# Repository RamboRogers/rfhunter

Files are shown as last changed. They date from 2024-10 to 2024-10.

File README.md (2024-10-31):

# RFHunter V4.0

This project is an RF Signal Scanner built using an ESP32, AD8317 RF detector, and various other components. It's designed to detect and measure RF signals in the environment and display the signal strength on an OLED display. It's useful to find hidden cameras, wiretapping devices, and other RF-enabled devices.

<center>RFHunter V4.0
</center>

See the video here: https://x.com/rogerscissp/status/1847721651359850985

## Updates

2024-10-30 First Tag from the Wild! [RFHunter on X](https://x.com/LukeSwitzer_/status/1851430655499919486)

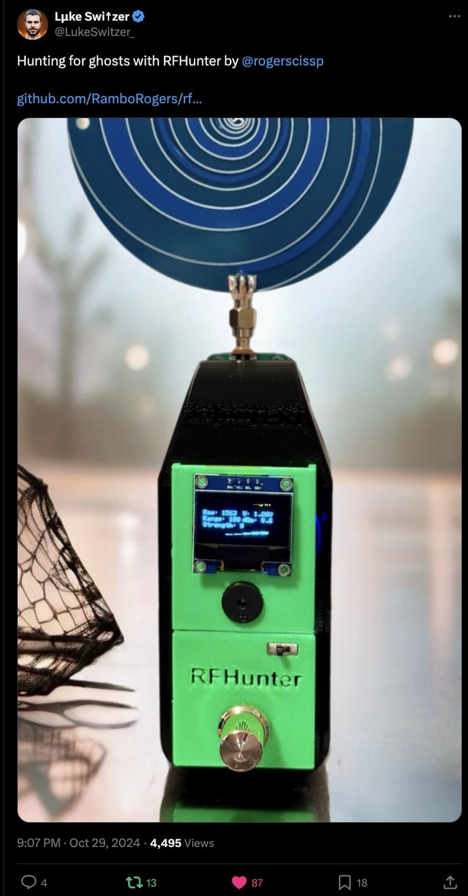
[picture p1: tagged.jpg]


2024-10-28 RFHunter hit #1 on hackernews this week!
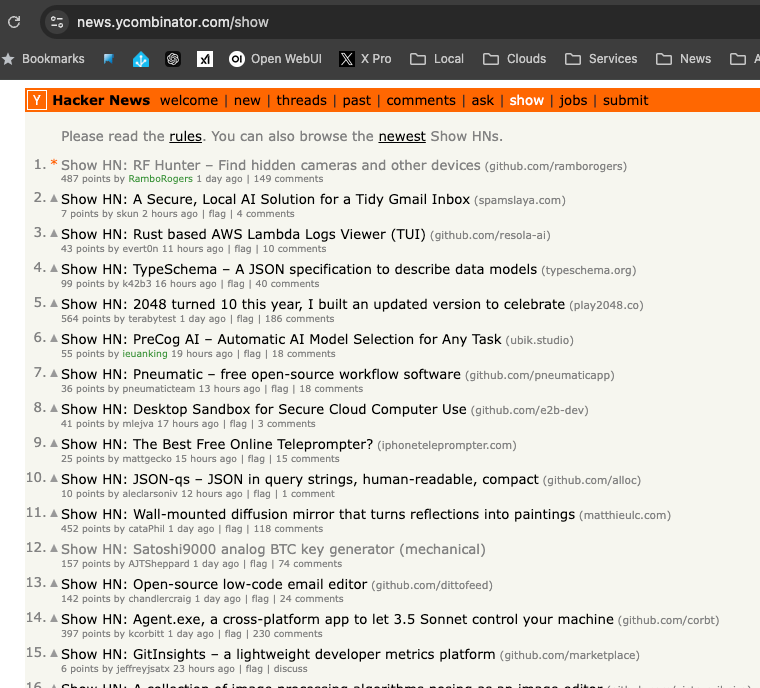
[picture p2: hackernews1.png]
Hacker News


I've have a number of interesting products in the works.  I'll share more details soon.

> **Note:** I've had some interesting comments under the issues section of this repo.  If you're making one of these you may want to look. It was suggest you could modif this board to not need a boost converter.  I've not tried this yet but I may give it a shot.  If you do please let me know how it goes.

## Ready for Primetime

V4 here snaps together with zero tools, has space in the bottom for a battery, and a charge controller, and in place of the 9V battery you have a boost converter.  Now you only need 1 battery, and it should last weeks or months depending on usage cycles.

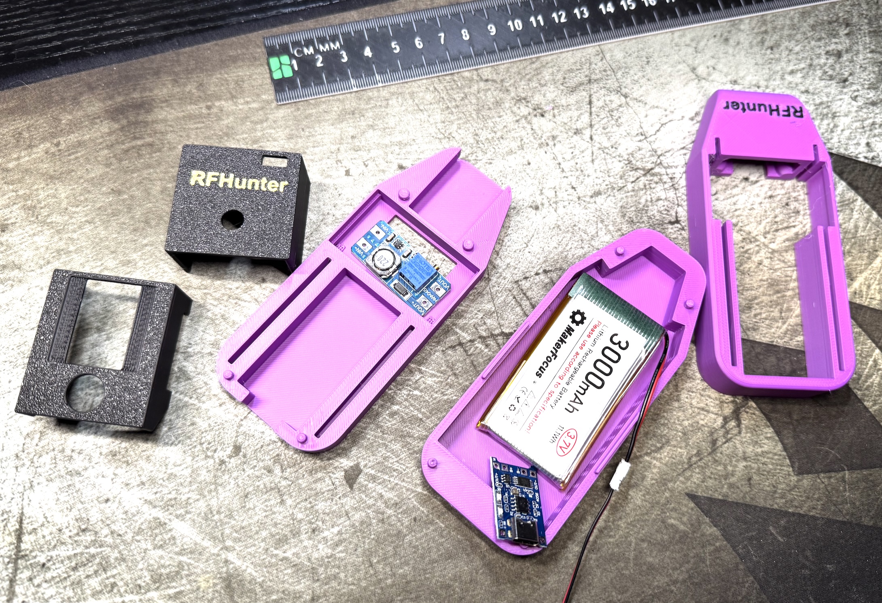
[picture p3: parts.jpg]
Parts


## Author

Matthew Rogers a simple hacker from the United States.
- Website: [matthewrogers.org](https://matthewrogers.org)
- Twitter: [@rogerscissp](https://x.com/rogerscissp)
- LinkedIn: [Matthew Rogers](https://www.linkedin.com/in/matthewrogerscissp/)

## License

This project is licensed under the GNU General Public License v3.0 (GNU GPLv3). See the [LICENSE](LICENSE) file for details.

## Bill of Materials (BOM)

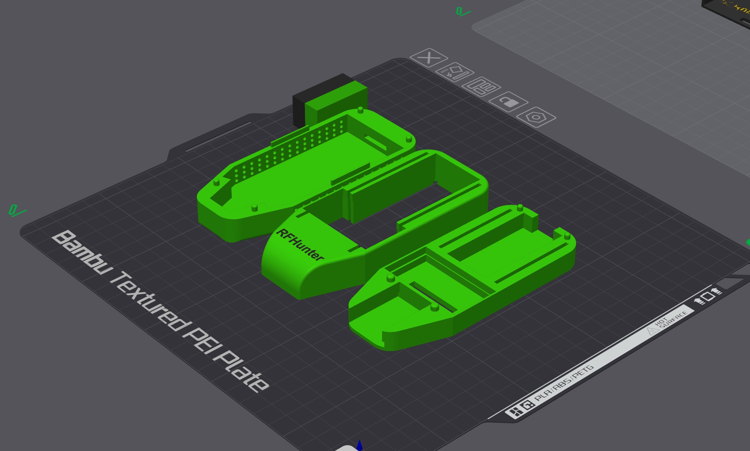
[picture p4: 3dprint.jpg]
3D Printed Parts


I listed the Amazon links in the .cpp file if you want to buy the parts. These are not affiliate links. You can buy these anywhere.

1. ESP32 Development Board
2. AD8317 RF Power Detector
3. TP4056 Lithium Battery Charge Controller
3.7V Lithium-ion Battery
4. Boost Converter (3.3V to 9V)
5. OLED Display (I2C, 128x64)
6. Potentiometer (10k)
7. Piezo Buzzer
8. Power Switch

## Build Process

1. Assemble the power circuit:
   - Connect the battery to the TP4056 charge controller
   - Connect the out from theTP4056 output to the power switch
   - Connect the power switch output to the ESP32 5v VIN and boost converter input
   - Adjust the boost converter output to 9V

  > Make sure the boost converter is set to 9V. If you don't have a boost converter, you can use a 9V battery.

  > Make sure you use the 5V VIN and not the 3.3V VIN.

2. Connect the AD8317 RF detector:
   - Power the AD8317 with the 9V output from the boost converter
   - Connect the VOUT pin to ESP32 GPIO 34

3. Set up the OLED display:
   - Connect VCC to ESP32 3.3V
   - Connect GND to ESP32 GND
   - Connect SDA to ESP32 GPIO 21
   - Connect SCL to ESP32 GPIO 22

4. Connect the potentiometer:
   - Connect VCC to ESP32 3.3V
   - Connect GND to ESP32 GND
   - Connect the wiper to ESP32 GPIO 35

5. Connect the piezo buzzer:
   - Connect the positive terminal to ESP32 GPIO 5
   - Connect the negative terminal to ESP32 GND

6. Flash the ESP32 with the provided code:

   ```
   git clone https://github.com/ramborogers/rfhunter.git
   cd rfhunter
   pio run -t upload
   ```
   >**You shouldn't need to change any of the code.**

7. Snap the case together

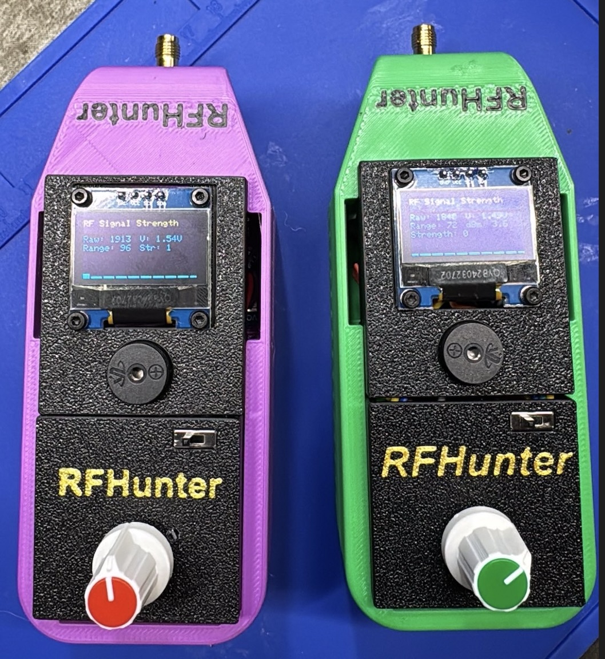
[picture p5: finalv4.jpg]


## Wiring Instructions

Wiring Guide for RFHunter:

### Power Circuit:
1. Battery (3.7V) positive terminal -> Power Switch
2. Power Switch -> TP4056 Charge Controller (B+)
3.TP4056 OUT+ -> ESP32 VIN and Boost Converter IN+
4. Boost Converter OUT+ (adjusted to 9V) -> AD8317 VCC
5. Battery negative terminal -> TP4056 B- and ESP32 GND and Boost Converter IN-
6. Boost Converter OUT- -> AD8317 GND

### Signal and Control:

7. AD8317 VOUT -> ESP32 GPIO 34 (RF_SENSOR_PIN)
8. Potentiometer VCC -> ESP32 3.3V
9. Potentiometer GND -> ESP32 GND
Potentiometer Wiper -> ESP32 GPIO 35 (POT_PIN)
10. OLED Display VCC -> ESP32 3.3V
11. OLED Display GND -> ESP32 GND
12. OLED Display SDA -> ESP32 GPIO 21 (OLED_SDA)
13. OLED Display SCL -> ESP32 GPIO 22 (OLED_SCL)
14. Piezo Buzzer positive -> ESP32 GPIO 5 (BUZZER_PIN)
15. Piezo Buzzer negative -> ESP32 GND

## Notes:

- The power switch controls the main power flow from the battery.
- The TP4056 charge controller manages battery charging and protection.
- The boost converter steps up the 3.3V from the battery to 9V for the AD8317 sensor.
- All GND connections should be common.
Double-check all connections and voltage levels before powering on.

## Usage

1. Power on the device using the power switch
2. The OLED display will show the current RF signal strength
3. Use the potentiometer to adjust the sensitivity
4. The piezo buzzer will sound when strong RF signals are detected

## Improvements and Feedback

We're always looking for ways to improve this project. If you have any ideas or suggestions, please feel free to open an issue or submit a pull request on our GitHub repository.

If you build your own RF Signal Scanner based on this project, we'd love to see it! Please share your creation on Twitter/X and tag @rogerscissp. Your feedback and experiences are valuable to the community!

Happy building!

Matthew Rogers

> The best idea for a date, his and hers RF Hunters!

<center>
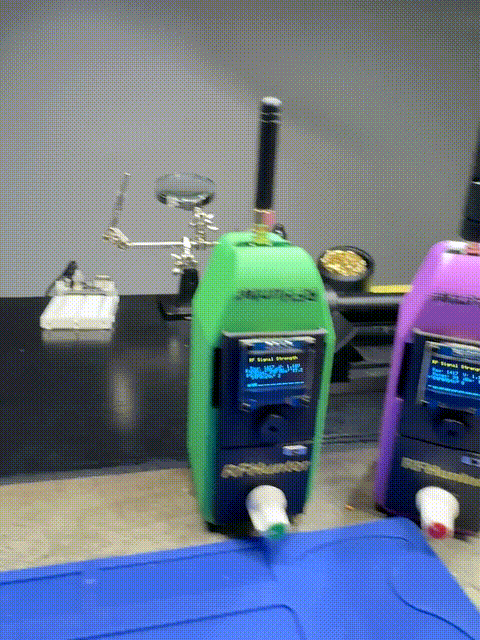
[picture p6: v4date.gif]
RFHunter V4.0

</center>

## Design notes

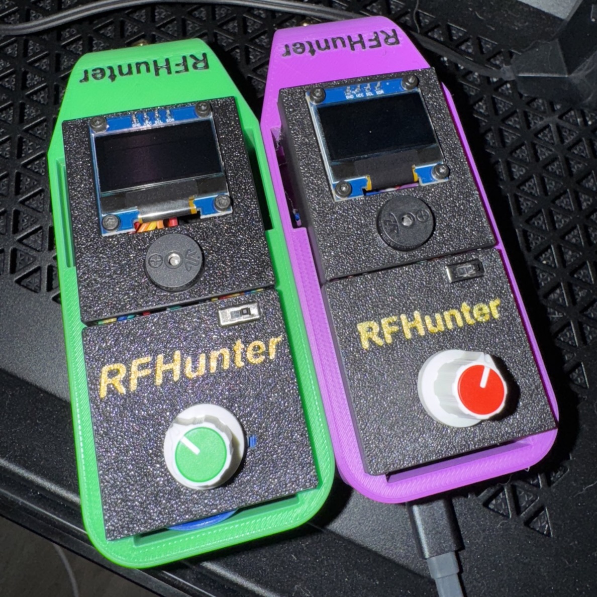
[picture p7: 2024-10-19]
built.jpg

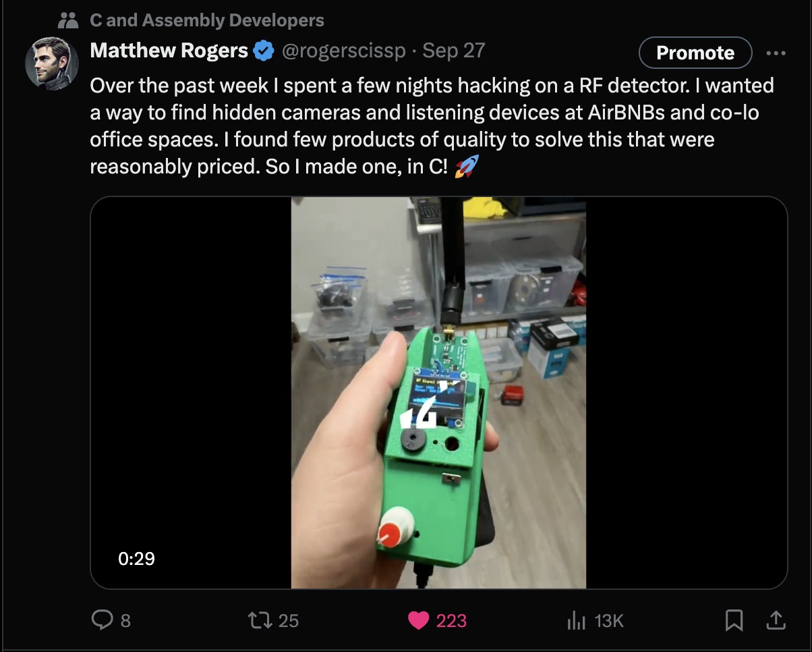
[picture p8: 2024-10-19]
xpost.jpg

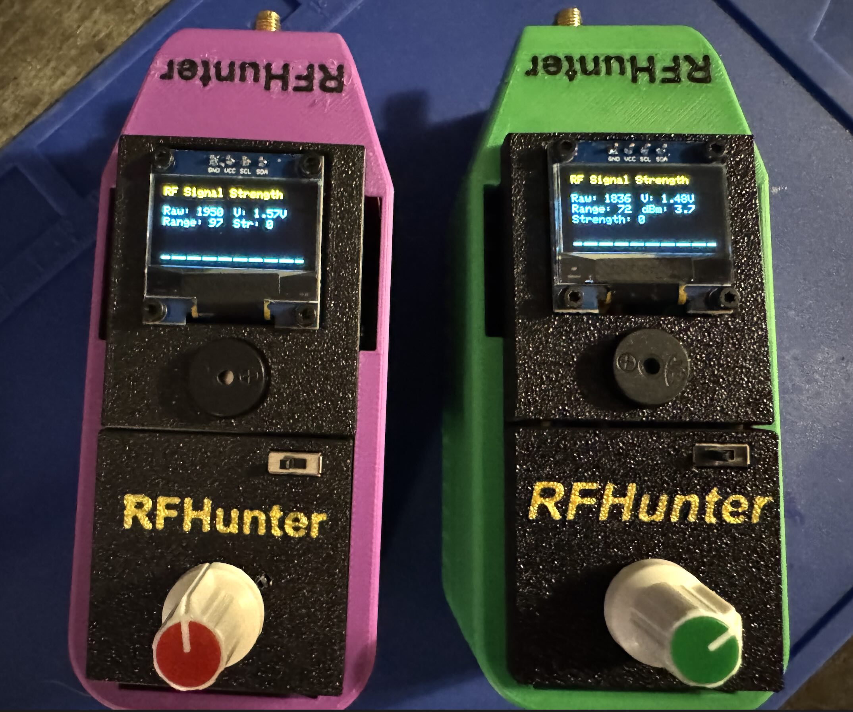
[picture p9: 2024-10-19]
builtv4.jpg

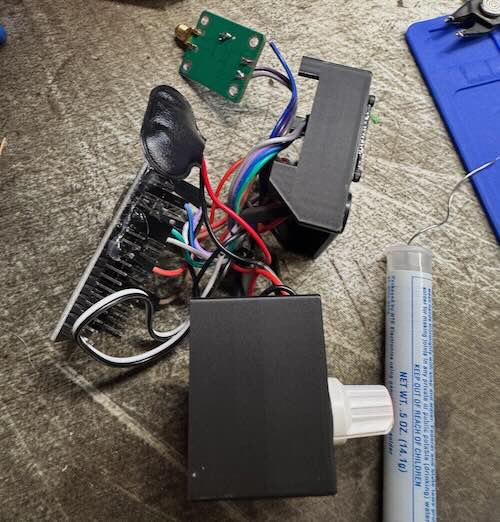
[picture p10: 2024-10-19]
wires.jpg

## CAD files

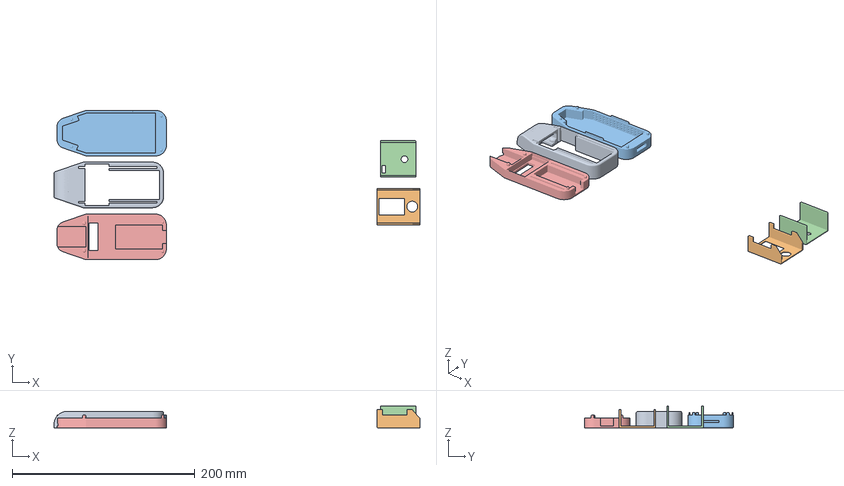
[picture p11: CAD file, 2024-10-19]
RFHunter-3DPrint-v10.3mf
400.8 x 163.6 x 24.0 mm
Top Hand
Grip
BatteryBox
BackTop
Middle

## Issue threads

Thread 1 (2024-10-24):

Bost converter isn't needed.

Kalrkloss, 2024-10-24:
The AD8317 itself can work from 3.0 to 5.5V.
The board you're using has a 5V regulator (78L05), that needs an input voltage of at least 7V.
If you replace the voltage regulator by a jumper wire, you can omit the boost converter, and also save some power.
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

EspressoTini, 2024-10-26:
Was just going to say the same, 9v not needed.  This chip would also be sweet on a credit card size pcb, coin cell battery, and LEDs for the signal stregth, for portability.  Maybe the antenna could be pcb too

RamboRogers, 2024-10-28:
Thats a cool idea!  I don't know the underlying design of the board, I just use it as a signal source.

RamboRogers, 2024-10-28:
Added note to README

lukeswitz, 2024-10-28:
I’m curious why this issue is closed.

Wow, this thing is huge! Its like a 90’s cordless phone. This could all be done on a single layer. Anyhow- the problem is indeed an issue from any objective electrical perspective. But if you’re ok with it “just working” then close away.

Removing the unit and jumping those pads indeed saves power and eliminates the need for the boost controller (that’s very prone to blowing the pot and worse from a simple search). Eliminating a point of failure and decreasing power consumption - win/win. At least link a reliable step-up to 9v or something.

Link to this closed issue in the readme perhaps. Good luck!

Closed 2024-10-28.

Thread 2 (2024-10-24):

How would this deal with all IoT gadgets?

X-Ryl669, 2024-10-24:
Since now house are filled with IoT stuff, emitting Zigbee, Wifi, Bluetooth, LoRa and so on, how does this gizmo can make a difference between a genuine gadget and camera?

What about the non RF camera that are storing the video on a local µSD card without being RF connected?

How about a cameras in a main appliance object (like a SmartTV or a sattelite receiver, which will emit RF anyway)?

Kalrkloss, 2024-10-24:
The IoT stuff usually sends only short bursts of data here and there, while an active camera sends a continuous stream of data, resulting in a constantly high field strength. You'll notice the difference.

X-Ryl669, 2024-10-24:
> You'll notice the difference.

Only if there's a client on the camera, which is extremely unlikely to happen at the time you're using the detector.

> Big surprise you cannot detect non-RF camera with RF detector, lol.

Well, my point is that the main page is trying to "sell" the idea that the device will detect cameras. But it won't.
Non RF camera will be undetected and RF camera won't likely be detected either (except in the very unlikely event that a client is connected and streaming from the camera at the exact time you're scanning the room).

But if you peak a WIFI burst (or any other radio burst), then it's even more likely it comes from the IoT gizmos than the camera itself. All devices (IoT and RF Camera) will have some (sparse) chatty transmission for maintaining their RF link, so there's ~ zero reason the RF activity is actually linked with a camera (well, close to zero in fact).

So maybe the main page should be modified to state that this is actually a RF detector for any RF emission in its receiving range and remove the part that reads `It's useful to find hidden cameras, wiretapping devices, and other RF-enabled devices.` because I don't see how you'll find hidden cameras with the detector, or a wiretapping device that, by definition will not use RF if they are wired.

Also, since there's no dual antenna, you can't trilaterate the signal either so, at best, you'll get a pseudo range to the source (since you don't know the source power, you can only make relative measurement => better / worse). Good luck finding a device that's emitting its WIFI beacon every 10s that way, with all the reflections.

BTW, I'm not criticizing the amazing work you've done. Just that the subtitle is misleading.

I think it should say something like "This device is able to detect RF emission, and measure the relative RF power received".

X-Ryl669, 2024-10-24:
> And if you really mean it, you need "Non-linear Junction Detector", prepare at least $10k. ;-)

When I was younger, I made a simple device that's detecting the electromagnetic field intensity. I was based on a cheap 1N4148 diode and a op amp + $1  micro controller (using its DAC and ADC). The basic physical principle was to bias the diode very close to the tripping point and ramp it up periodically. The "avalanche" effect, where the current grows exponentially triggers from ambient EM field (plus temperature, plus ..., but RF field effect is observable and temperature is usually constant).
By periodically counting the time it takes for the diode to become conductive, you get a signal proportional to RF activity.

The overall cost for the device was very low. I've just lost interest with playing with it very fast.

You can search for diode RF tester for simple schematic from the very basic to the most efficient design.

RamboRogers, 2024-10-26:
This device detects long streams and signals.  I don't care about short bursts.  It's also barelines on bootup so it will alert off baseline.  If you turn it on directly next to AP it's unlikely it will alarm much after.  You want to power it on and it will alert as you get close to a higher signal versus baseline.

Closed 2024-10-26.

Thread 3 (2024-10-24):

Battery voltage

michaelmior, 2024-10-24:
The README appears to have a typo.

> If you don't have a **<ins>9V battery</ins>**, you can use a **<ins>9V battery</ins>**.

RamboRogers, 2024-10-26:
Thanks, fixed.

Closed 2024-10-26.

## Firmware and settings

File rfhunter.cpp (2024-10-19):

#include <Arduino.h>
#include <Wire.h>
#include <Adafruit_GFX.h>
#include <Adafruit_SSD1306.h>
#include <math.h>

/*

RFHunter V4.01

Code is property of Matthew Rogers, 2024 matthewrogers.org
This code is free to use under the GNU GPLv3 license.

https://x.com/rogerscissp

2024-10-19 V4.01 - Added a display recovery mechanism in case the display is not found on startup.

*/

/*
I'm including the parts I used in the BOM. I've included links to Amazon, but these are not affiliate links. You can buy these anywhere.

The attached 3mf file is the case I designed in Fusion 360. You'll want to use supports to print it, but it's aligned on the bed properly in two separate plates. All of these parts clip in perfectly.

Parts
1. ESP-WROOM-32 - https://www.amazon.com/gp/product/B08D5ZD528
2. AD8317 - https://www.amazon.com/gp/product/B07FHZXTCZ
3. 10k Potentiometer - https://www.amazon.com/gp/product/B0CSW6D1N4
5. 3000mah Battery - https://www.amazon.com/gp/product/B08T6GT7DV
6. Charge Controller - https://www.amazon.com/gp/product/B08DNK398S
7. Boost Converter - https://www.amazon.com/gp/product/B09S8ZDVBN
8. 128x64 OLED Display - https://www.amazon.com/gp/product/B0D2RLXLBZ
9. Piezo Buzzer - https://www.amazon.com/Cylewet-Terminals-Electronic-Electromagnetic-Impedance/dp/B01NCOXB2Q
10. Power Switch - https://www.amazon.com/gp/product/B007QAJUUS

Consumables and Tools
1. Dupont Wires - https://www.amazon.com/gp/product/B01EV70C78
2. Solder and Soldering Iron - https://www.amazon.com/gp/product/B0CZ94B328
3. Wire Stripper - https://www.amazon.com/gp/product/B0B4J8C8FD
*/

/*
Wiring Guide for RF Signal Scanner:

Power Circuit:
1. Battery (3.7V) positive terminal -> Power Switch
2. Power Switch -> ESP32 5v VIN and Boost Converter IN+
4. Boost Converter OUT+ (adjusted to 9V) -> AD8317 VCC
5. Battery negative terminal -> TP4056 B- and ESP32 GND and Boost Converter IN-
6. Boost Converter OUT- -> AD8317 GND

Signal and Control:
7. AD8317 VOUT -> ESP32 GPIO 34 (RF_SENSOR_PIN)
8. Potentiometer VCC -> ESP32 3.3V
9. Potentiometer GND -> ESP32 GND
10. Potentiometer Wiper -> ESP32 GPIO 35 (POT_PIN)
11. OLED Display VCC -> ESP32 3.3V
12. OLED Display GND -> ESP32 GND
13. OLED Display SDA -> ESP32 GPIO 21 (OLED_SDA)
14. OLED Display SCL -> ESP32 GPIO 22 (OLED_SCL)
15. Piezo Buzzer positive -> ESP32 GPIO 5 (BUZZER_PIN)
16. Piezo Buzzer negative -> ESP32 GND

Notes:
- The power switch controls the main power flow from the battery.
- The TP4056 charge controller manages battery charging and protection.
- The boost converter steps up the 3.3V from the battery to 9V for the AD8317 sensor.
- All GND connections should be common.
- Double-check all connections and voltage levels before powering on.
*/

#define SCREEN_WIDTH 128 // OLED display width, in pixels
#define SCREEN_HEIGHT 64 // OLED display height, in pixels

// Pin definitions for ESP32
#define RF_SENSOR_PIN 34   // ADC1_CH6 (GPIO 34)
#define POT_PIN 35         // ADC1_CH7 (GPIO 35)
#define OLED_SDA 21        // Default SDA pin for ESP32
#define OLED_SCL 22        // Default SCL pin for ESP32
#define BUZZER_PIN 5       // You can choose any digital pin

Adafruit_SSD1306 display(SCREEN_WIDTH, SCREEN_HEIGHT, &Wire, -1);

const int numReadings = 20;
int readings[numReadings];
int readIndex = 0;
long total = 0;

int baselineRaw = 0;
int minRaw = 4095;  // ESP32 ADC is 12-bit (0-4095)
int maxRaw = 0;

float rawToVoltage(int raw) {
  return raw * (3.3f / 4095.0f);  // ESP32 ADC is 12-bit
}

int getBaselineRange() {
  int potValue = analogRead(POT_PIN);
  // Map potentiometer value to 0-200 range
  return map(potValue, 0, 4095, 0, 200);
}

// AD8317 specific constants
const float V_MIN = 0.33f;  // Minimum output voltage
const float V_MAX = 1.65f;  // Maximum output voltage
const float SLOPE = -22.0f; // mV/dB
const float INTERCEPT = 0.0f; // dBm at V_MAX (adjusted)

float voltageTodBm(float voltage) {
  if (voltage < V_MIN) return -70.0f;
  if (voltage > V_MAX) return 0.0f;
  return SLOPE * (voltage - V_MAX) + INTERCEPT;
}

void setup() {
  Serial.begin(115200);
  delay(1000);
  Serial.println(F("\n\nRF Signal Scanner - ESP32 with AD8317"));

  // Initialize I2C communication for the display
  Wire.begin(OLED_SDA, OLED_SCL);

  // Try to initialize the display multiple times if needed
  bool displayInitialized = false;
  for (int attempt = 0; attempt < 3 && !displayInitialized; attempt++) {
    if (display.begin(SSD1306_SWITCHCAPVCC, 0x3C)) {
      displayInitialized = true;
    } else {
      Serial.println(F("SSD1306 allocation failed, retrying..."));
      // Perform a soft reset by reinitializing I2C
      Wire.end();
      delay(100);
      Wire.begin(OLED_SDA, OLED_SCL);
      delay(100);
    }
  }

  if (!displayInitialized) {
    Serial.println(F("SSD1306 allocation failed after multiple attempts"));
    // You can decide to continue or halt the program here
  } else {
    display.clearDisplay();
    display.setTextSize(1);
    display.setTextColor(SSD1306_WHITE);

    // Display initialization success message
    display.setCursor(0, 0);
    display.println(F("Display initialized"));
    display.display();
    delay(1000);
  }

  pinMode(RF_SENSOR_PIN, INPUT);
  pinMode(POT_PIN, INPUT);
  pinMode(BUZZER_PIN, OUTPUT);

  // Establish baseline
  long sum = 0;
  for (int i = 0; i < 100; i++) {
    sum += analogRead(RF_SENSOR_PIN);
    delay(10);
  }
  baselineRaw = sum / 100;
  minRaw = maxRaw = baselineRaw;

  Serial.print(F("Baseline Raw: "));
  Serial.println(baselineRaw);

  display.clearDisplay();
  display.setCursor(0, 0);
  display.println(F("RF Signal Scanner"));
  display.setCursor(0, 16);
  display.print(F("Baseline: "));
  display.println(baselineRaw);
  display.display();
  delay(2000);

  for (int i = 0; i < numReadings; i++) {
    readings[i] = baselineRaw;
  }
  total = baselineRaw * numReadings;

  Serial.println(F("Setup complete"));
}


void loop() {
  int baselineRange = getBaselineRange();

  total = total - readings[readIndex];
  readings[readIndex] = analogRead(RF_SENSOR_PIN);
  total = total + readings[readIndex];
  readIndex = (readIndex + 1) % numReadings;

  int average = total / numReadings;

  if (average < minRaw) minRaw = average;
  if (average > maxRaw) maxRaw = average;

  float voltage = rawToVoltage(average);
  float dBm = voltageTodBm(voltage);
  int signalStrength = 0;
  if (baselineRange > 0) {
    signalStrength = map(average, baselineRaw, baselineRaw - baselineRange, 0, 10);
    signalStrength = constrain(signalStrength, 0, 10);
  }

  Serial.print(F("Raw: "));
  Serial.print(average);
  Serial.print(F(" Range: "));
  Serial.print(baselineRange);
  Serial.print(F(" V: "));
  Serial.print(voltage, 3);
  Serial.print(F("V dBm: "));
  Serial.print(dBm, 1);
  Serial.print(F(" Strength: "));
  Serial.println(signalStrength);

  display.clearDisplay();

  // Title
  display.setTextSize(1);
  display.setCursor(0, 0);
  display.println(F("RF Signal Strength"));

  // Raw value and voltage
  display.setCursor(0, 16);
  display.print(F("Raw: "));
  display.print(average);
  display.setCursor(64, 16);
  display.print(F("V: "));
  display.print(voltage, 2);
  display.print(F("V"));

  // Range and dBm
  display.setCursor(0, 26);
  display.print(F("Range: "));
  display.print(baselineRange);
  display.setCursor(64, 26);
  display.print(F("dBm: "));
  display.print(dBm, 1);

  // Signal strength
  display.setCursor(0, 36);
  display.print(F("Strength: "));
  display.print(signalStrength);

  // Draw signal strength bars
  int barWidth = 12;
  int barSpacing = 2;
  int startX = (SCREEN_WIDTH - (barWidth * 10 + barSpacing * 9)) / 2;
  int barMaxHeight = 20;

  for (int i = 0; i < 10; i++) {
    int barHeight = (i < signalStrength) ? map(i, 0, 9, 5, barMaxHeight) : 2;
    display.fillRect(startX + i * (barWidth + barSpacing), SCREEN_HEIGHT - barHeight, barWidth, barHeight, SSD1306_WHITE);
  }

  display.display();

  // Beep based on signal strength
  if (signalStrength > 0) {
    int freq = map(signalStrength, 1, 10, 500, 2000);
    tone(BUZZER_PIN, freq, 50);
  }

  delay(100);
}
